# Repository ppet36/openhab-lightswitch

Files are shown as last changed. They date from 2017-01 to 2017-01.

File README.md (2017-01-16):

# OpenHAB light switch

This repository encapsulates Cadsoft's Eagle files and firmware for OpenHAB light switch using ESP8266-01 module. There is single variant under switch with relay and single/double variants with relays/triacs for round wiring boxes.

For powering module can be used any 5V/ >=800mA power supply such as USB charger for phone. Power consumption with AKYGA CCABKEYAKY-07310 power supply is about 1.2W.

Schematics is very simple. For single variant GPIO0 of ESP8266 is used for driving relay/triac and GPIO2 for observation of original switch. Light can be turned on / off using original switch or OpenHAB admin screen. For double variant is used I/O expander PCA9536 which two pins used for driving relays/triacs and other two for switches observation.

For uploading code to ESP8266 is needed Arduino. In source code is needed to specify WIFI AP parameters, network parameters, OpenHAB item name as well as address where OpenHAB server listens. After module startup is on his IP address available HTTP server where some parameters can be redefined. It's useful in case for example changing WIFI password.

For handle lightswitch in OpenHAB you need to modify you sitemap, items and rules file. In items file (/configurations/items/&lt;yourname&gt;.items) is needed to define new item:
```
Switch bathroomMirror "Bathroom (mirror light)"
```
Now you can define rule in rules file (/configurations/rules/&lt;yourname&gt;.rules), which sends request to IP address of module whenever the status changes. Instead of 192.168.128.200 is need to specify IP address of your module.
```
rule bathroomMirror
when
  Item bathroomMirror changed
then 
  if (bathroomMirror.state == ON) {
    sendHttpGetRequest("http://192.168.128.200:80/ON")
  } else {
    sendHttpGetRequest("http://192.168.128.200:80/OFF")
  }
end 
```
Finally can be switch presented in sitemap file (/configurations/sitemaps/&lt;yourname&gt;.sitemap):
```
Switch item=bathroomMirror
```
It's easy and it looks pretty good:



##Schematics:
### Single relay
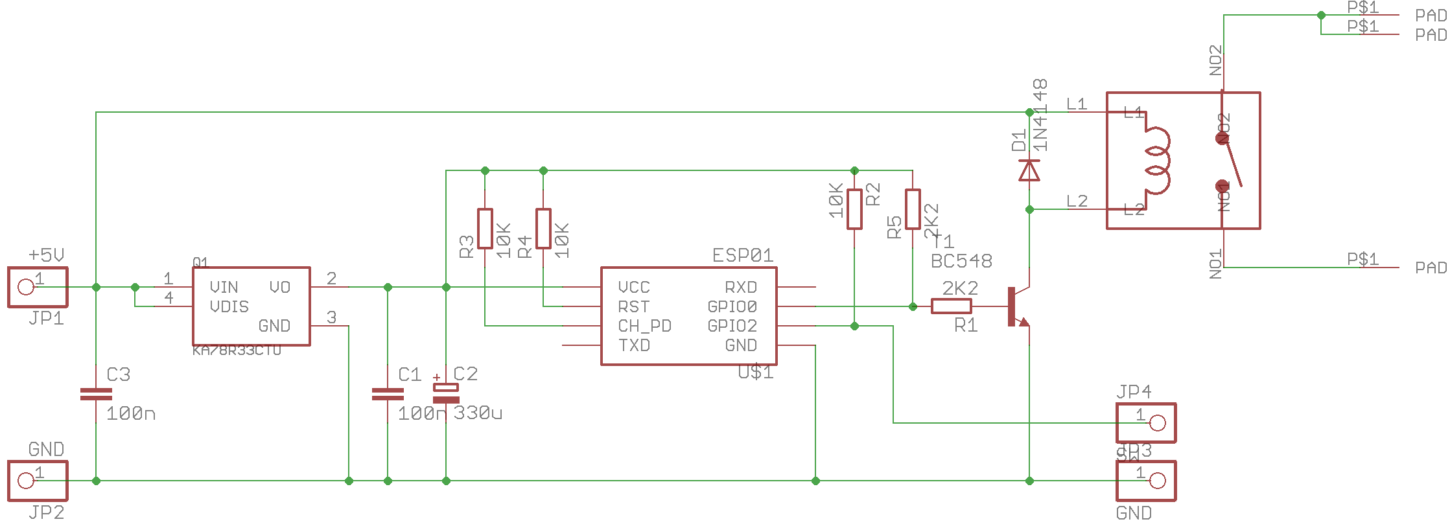
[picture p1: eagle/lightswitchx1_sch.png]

### Double relay
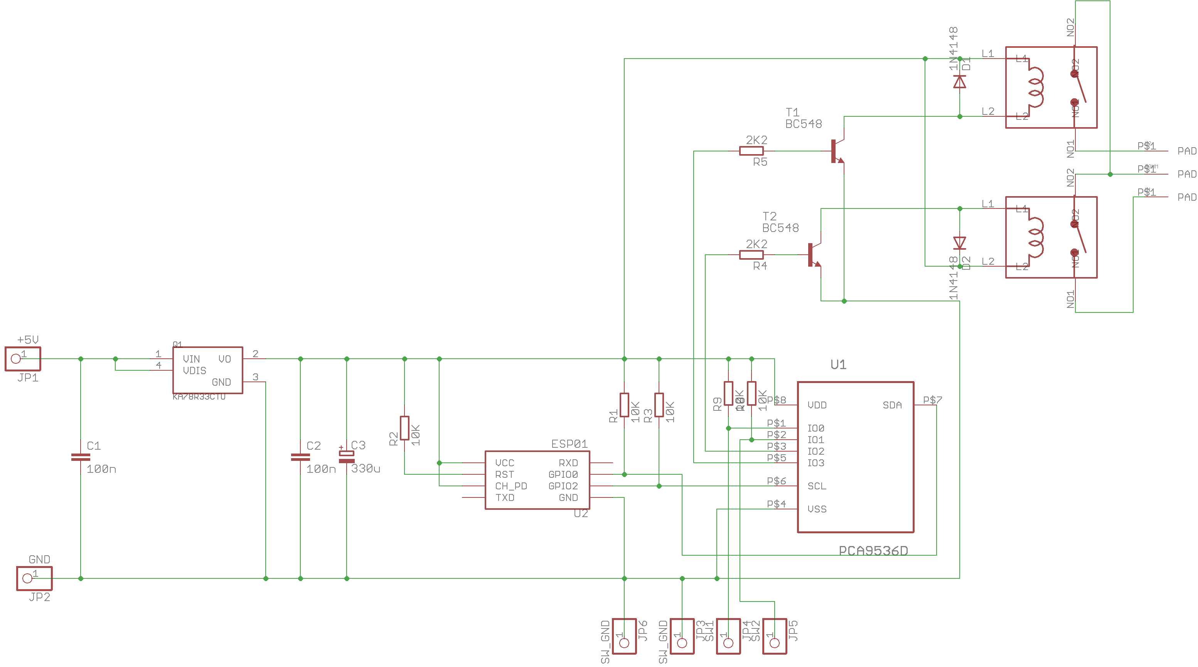
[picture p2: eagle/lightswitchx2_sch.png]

### Single triac
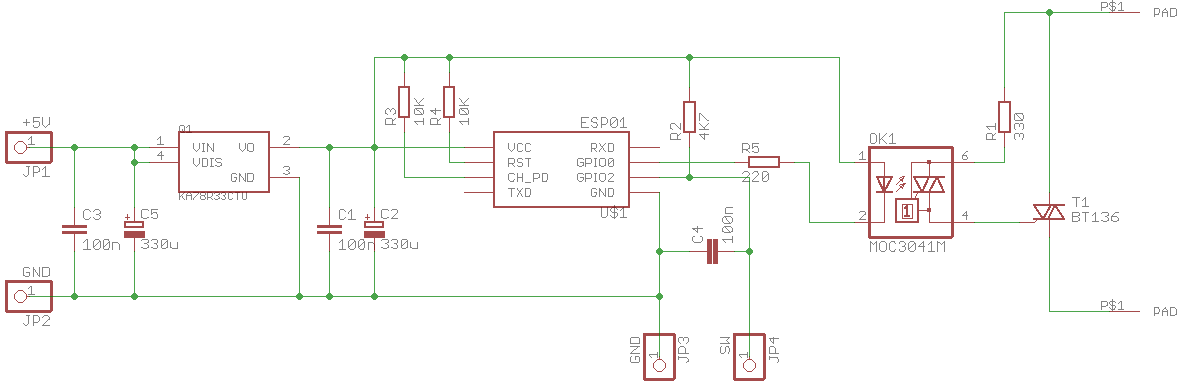
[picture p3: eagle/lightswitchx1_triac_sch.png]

### Double triac
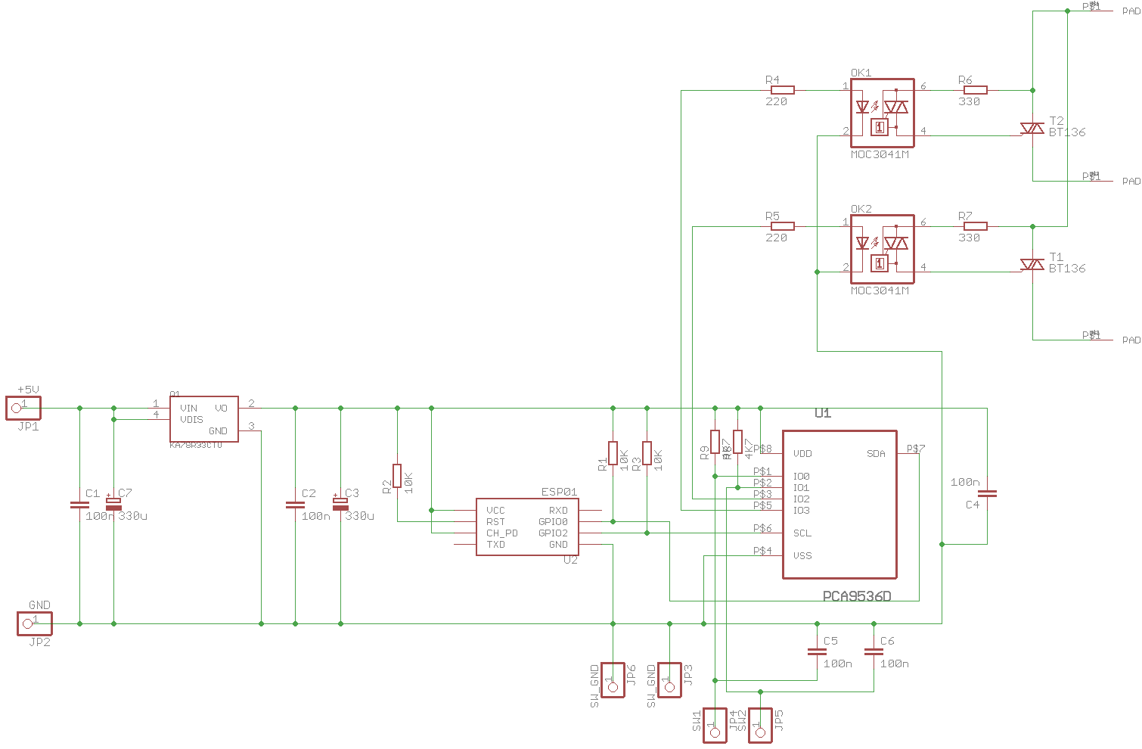
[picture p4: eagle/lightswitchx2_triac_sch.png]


##PCBs:
PCB is realized as single-sided with some wire jumpers. ESP8266 is mounted as always in socket to enable firmware update. Depending of interferences you may need solder some 100n capacitors directly to ICs pads from bottom side of PCB.

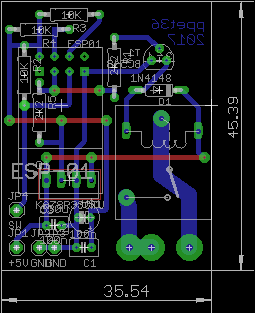
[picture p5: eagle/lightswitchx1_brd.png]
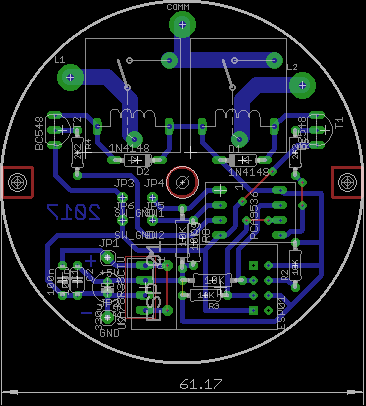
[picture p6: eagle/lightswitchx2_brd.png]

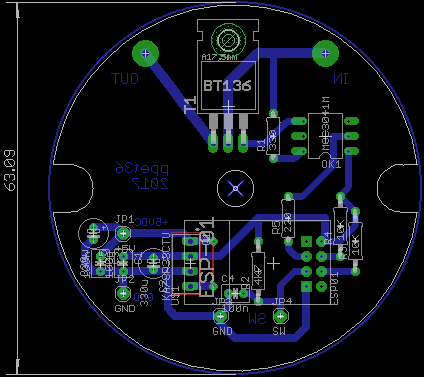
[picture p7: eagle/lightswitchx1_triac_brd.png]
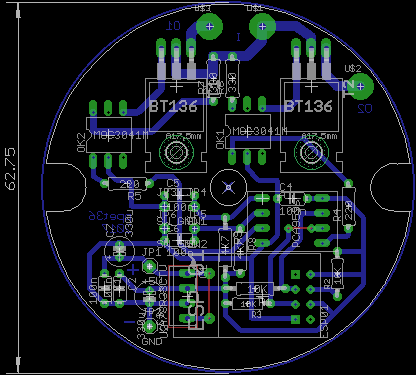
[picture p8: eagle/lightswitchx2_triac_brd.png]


###Some project images:

Module with power supply

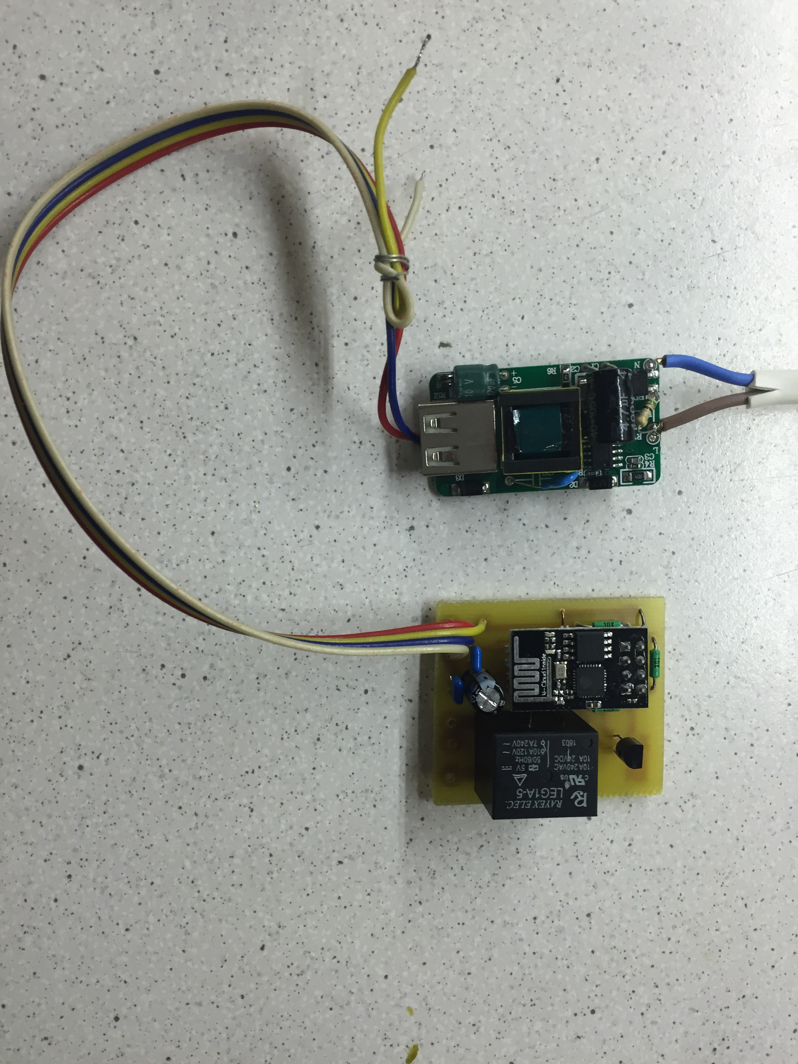
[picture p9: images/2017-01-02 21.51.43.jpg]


Already mounted on its place

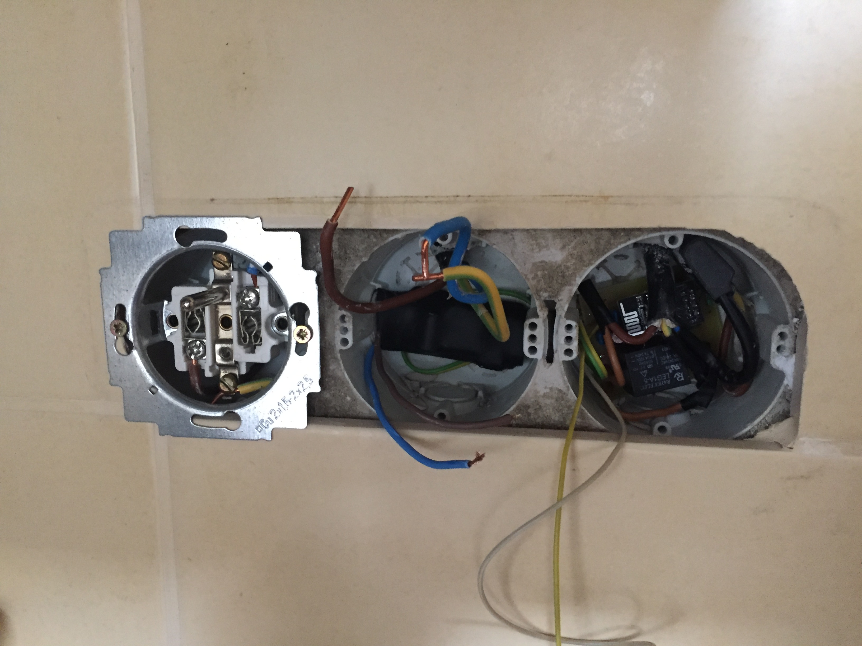
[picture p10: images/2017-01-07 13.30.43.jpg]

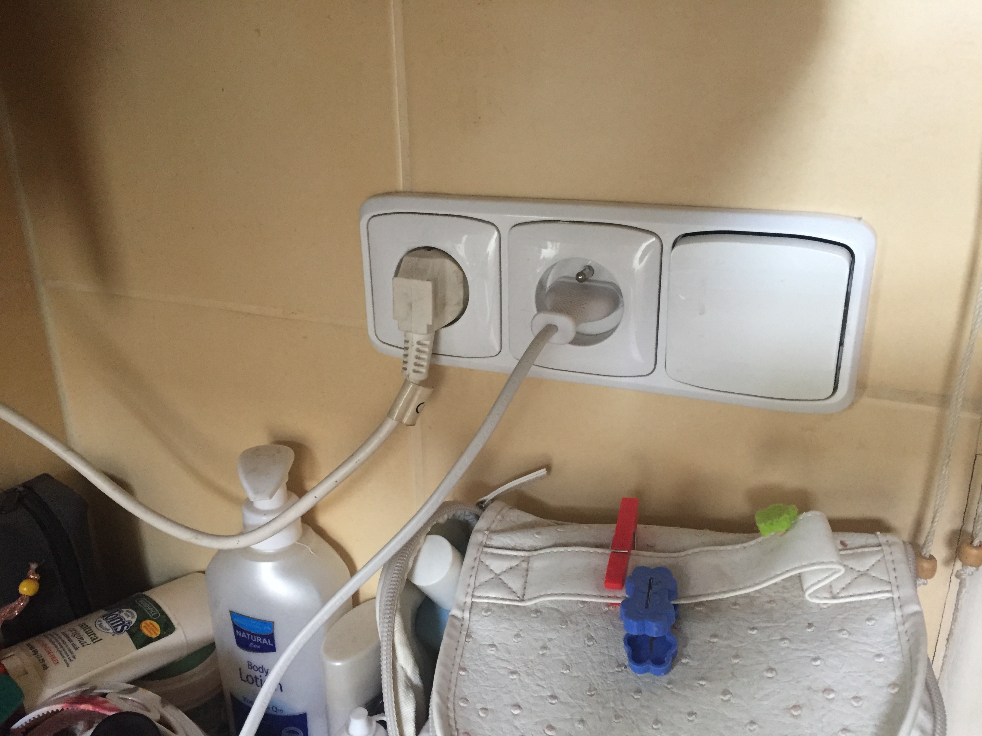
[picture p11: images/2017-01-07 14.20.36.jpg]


PCA9536 breadboard modules

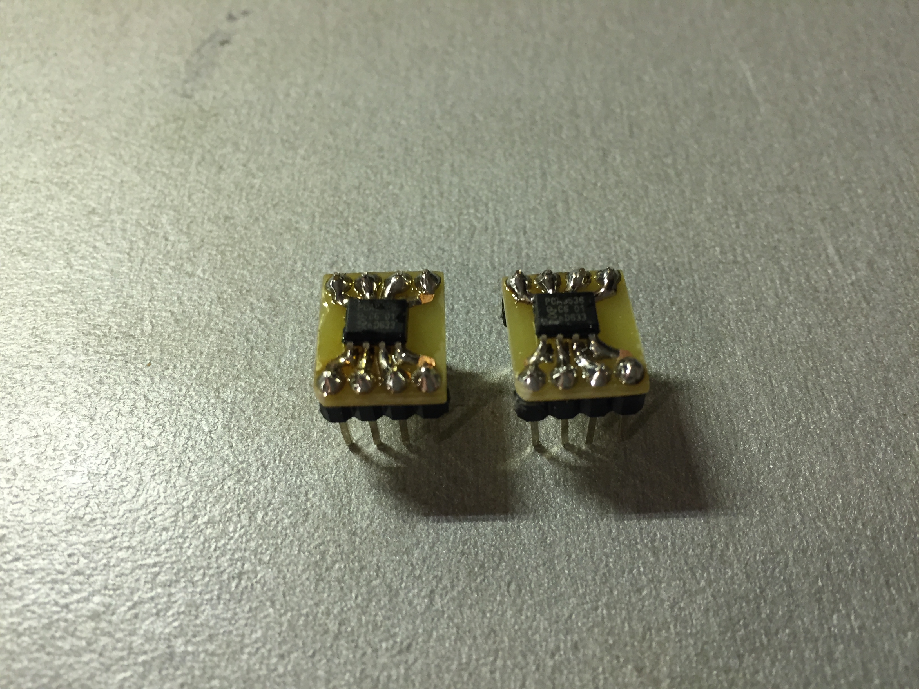
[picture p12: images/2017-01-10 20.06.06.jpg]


Double relay version

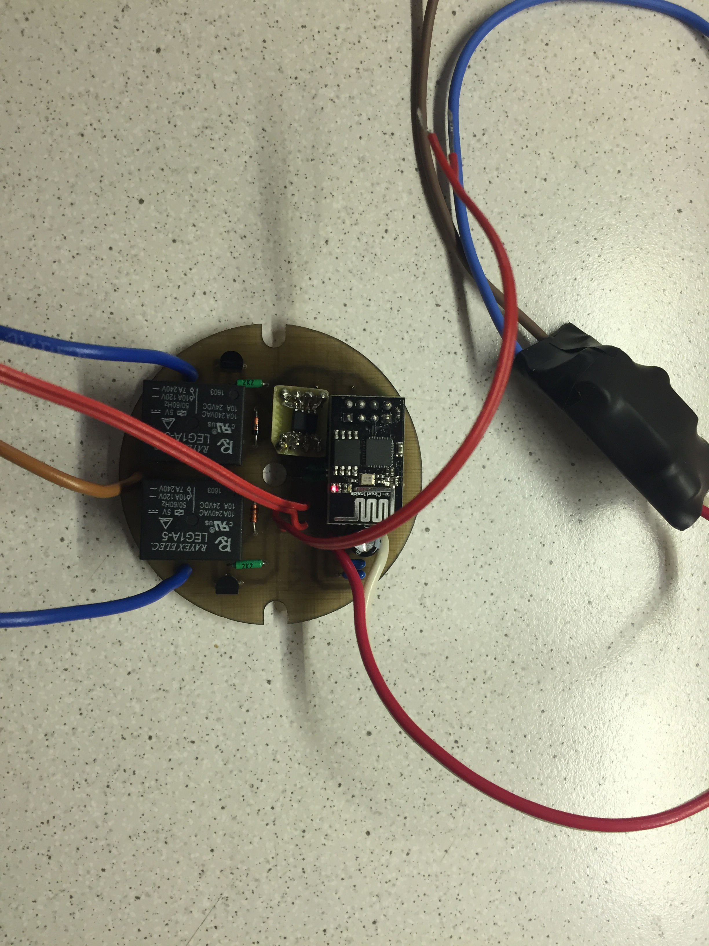
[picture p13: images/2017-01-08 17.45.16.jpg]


Single triac version

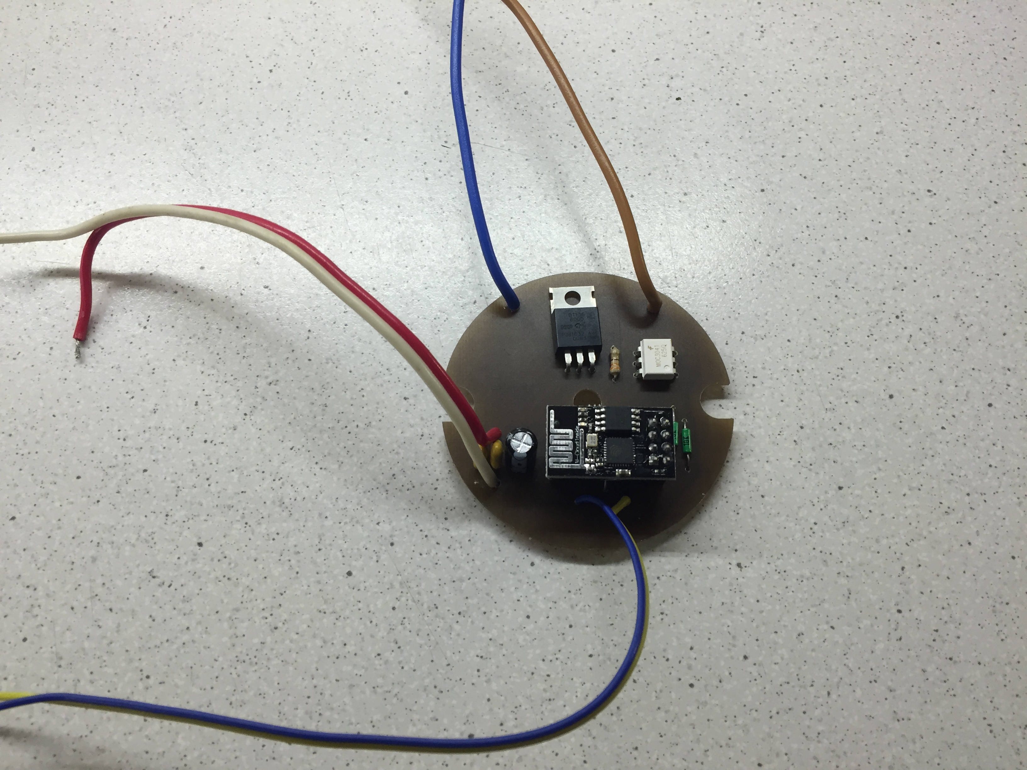
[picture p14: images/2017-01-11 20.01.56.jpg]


Double triac version

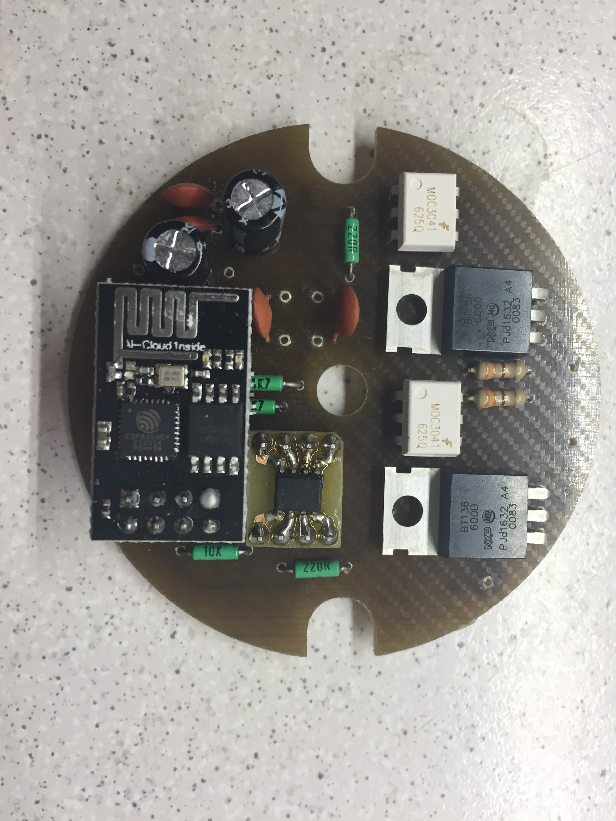
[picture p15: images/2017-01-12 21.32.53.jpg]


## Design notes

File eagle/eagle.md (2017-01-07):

This is schematic and PCB files for Cadsoft's Eagle.

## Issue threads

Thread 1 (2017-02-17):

How to load code on ESP8266

jamipraveeen, 2017-02-17:
I need to automate my applianes using OPENHAB2.I have installed Openhab2 on my raspberry pi and now my problem is how to control relays according to the user input using ESP8266.Can I control without Esp8266 ?I mean only with relay board connecting inputs to GPIO Pins of Raspberry pi? If not please provide me circuit diagram for connection

ppet36, 2017-02-21:
Here is short tutorial how to connect relay to raspberrypi gpio pin http://www.susa.net/wordpress/2012/06/raspberry-pi-relay-using-gpio/. On OpenHab website is also information how to map gpio pin to item: https://github.com/openhab/openhab1-addons/wiki/GPIO-Binding

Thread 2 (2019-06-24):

Connect original light switch on GPIO2

MaikoHermans, 2019-06-24:
I'm currently building a similar switch, however I'm not sure on how to track the state when the hardware switch is used. Do I need to connect a wire from the hardware switch to the board as well?

I'm actually using a relay board specifically made for the esp01 (see link) I would love to hear how to set this part up since I'm not sure how to make sense of the schematics you posted.

https://www.aliexpress.com/item/5V-ESP8266-ESP-01-Wifi-Relay-Module-Wireless-App-Remote-Control-IOT-Relay-Switch-ESP8266-ESP01/32963300866.html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

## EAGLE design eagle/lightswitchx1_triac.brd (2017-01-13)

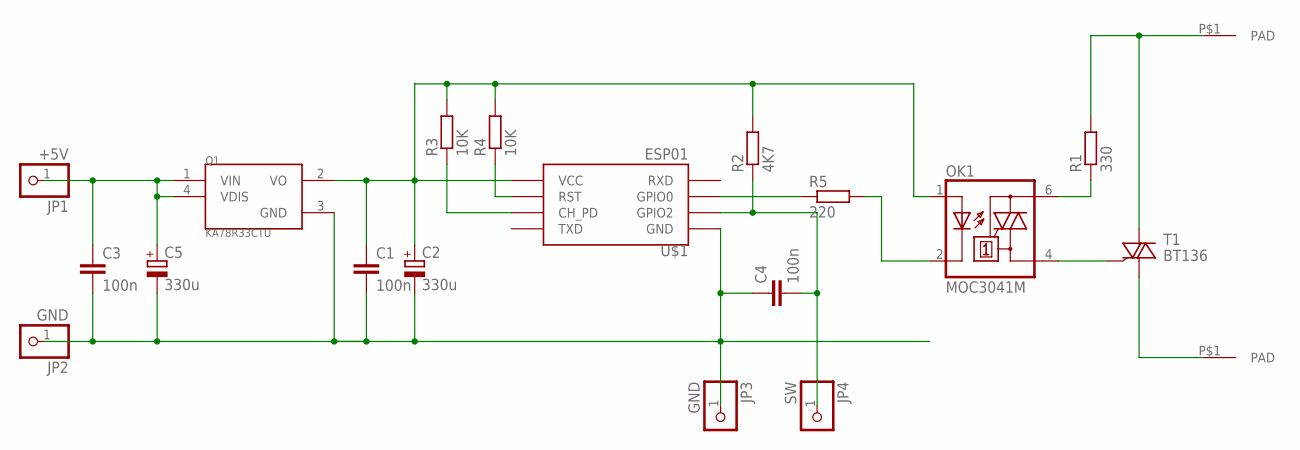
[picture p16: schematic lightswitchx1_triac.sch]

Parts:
C1, C3, C4: 100n; C025-030X050
C2, C5: 330u; E2-5
JP1: +5V; 1X01
JP2, JP3: GND; 1X01
JP4: SW; 1X01
OK1: MOC3041M; DIL06
Q1: KA78R33CTU; TO-220-4
R1: 330; 0207/7
R2: 4K7; 0207/10
R3, R4: 10K; 0207/10
R5: 220; 0207/7
T1: BT136; TO220AB
U$1: ESP01
U$4, U$5: PAD

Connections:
unnamed: C4.2, JP4.1, R2.1, U$1.GPIO2
unnamed: C1.2, C2.-, C3.2, C4.1, C5.-, JP2.1, JP3.1, Q1.3 (GND), U$1.GND
unnamed: C1.1, C2.+, OK1.1 (A), Q1.2 (VO), R2.2, R3.2, R4.2, U$1.VCC
unnamed: OK1.4 (A1), T1.3 (G)
unnamed: C3.1, C5.+, JP1.1, Q1.1 (VIN), Q1.4 (VDIS)
unnamed: R5.1, U$1.GPIO0
unnamed: OK1.6 (A2), R1.1
unnamed: R4.1, U$1.RST
unnamed: R3.1, U$1.CH_PD
unnamed: R1.2, T1.2 (A2), U$5.P$1
unnamed: T1.1 (A1), U$4.P$1
unnamed: OK1.2 (C), R5.2

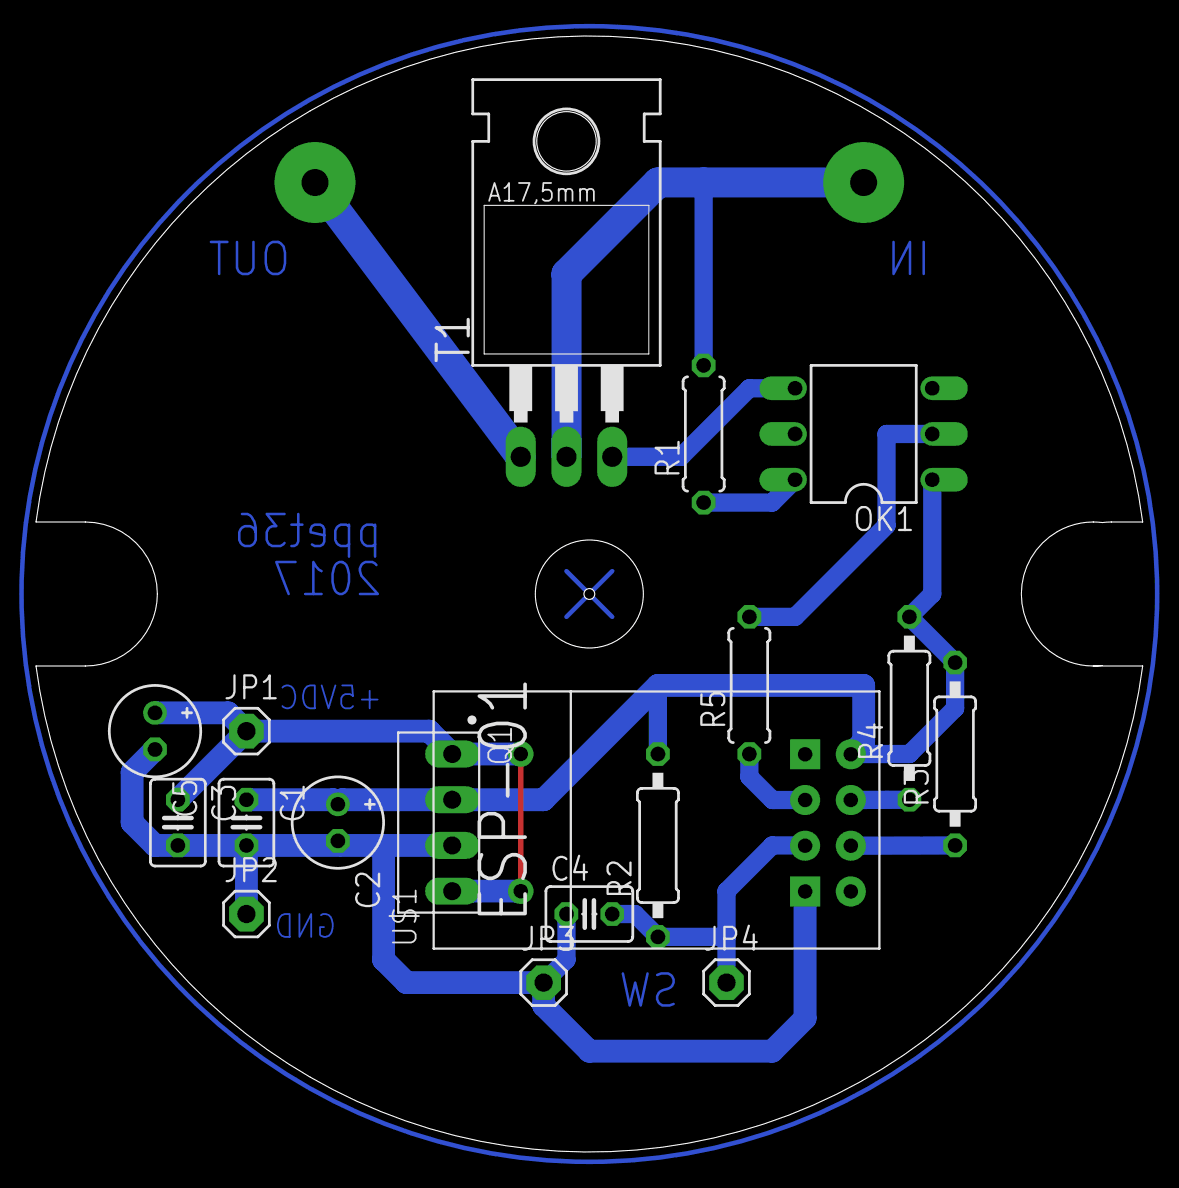
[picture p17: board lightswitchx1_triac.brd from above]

Board: 2 copper layers, 61.5 x 62.0 mm, 20 parts (0 on the bottom side), 12 nets.

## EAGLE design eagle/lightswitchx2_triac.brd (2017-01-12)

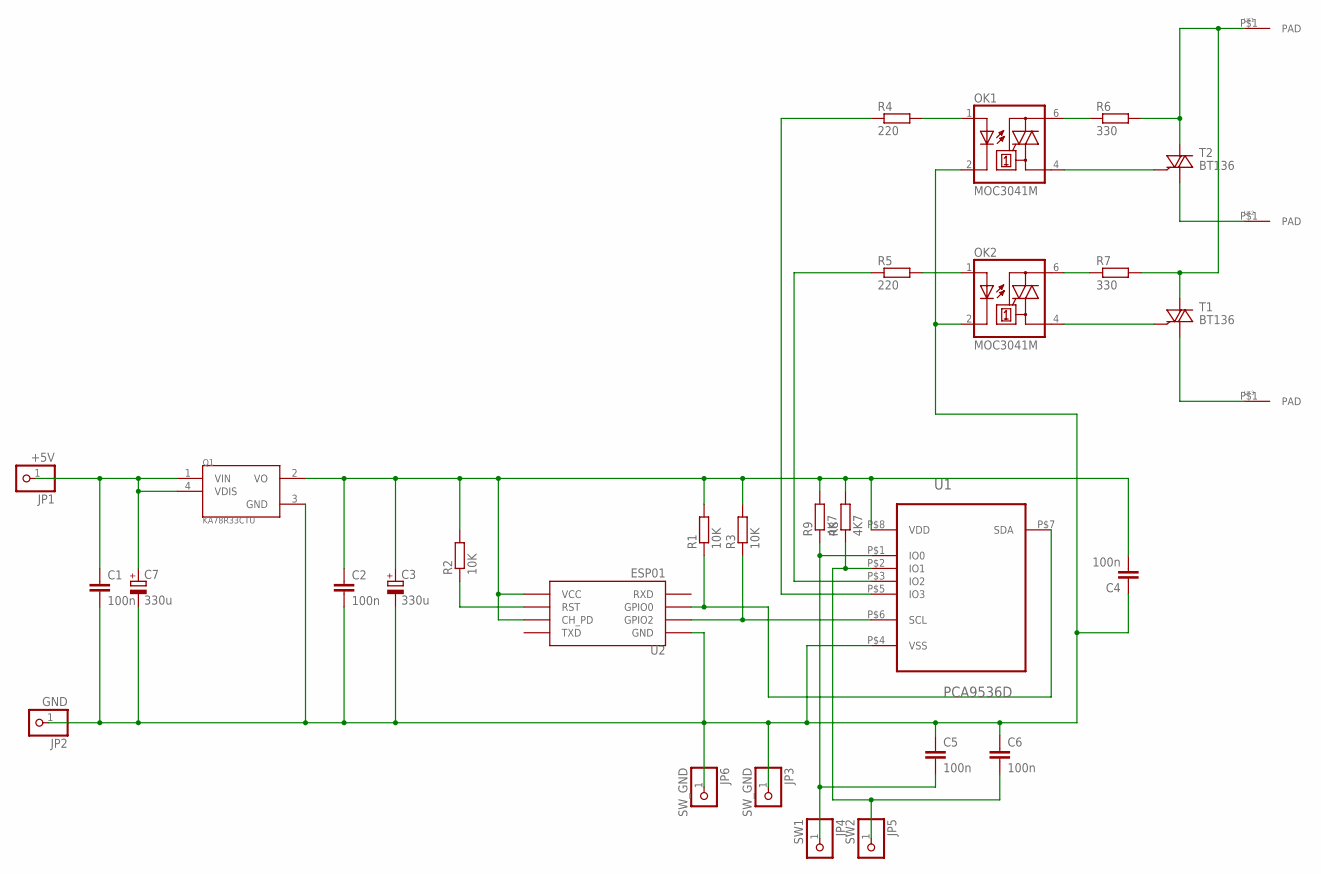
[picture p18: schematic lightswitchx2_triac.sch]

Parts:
C1, C2, C4, C5, C6: 100n; C050-024X044
C3, C7: 330u; E2-5
JP1: +5V; 1X01
JP2: GND; 1X01
JP3, JP6: SW_GND; 1X01-CLEANBIG
JP4: SW1; 1X01-CLEANBIG
JP5: SW2; 1X01-CLEANBIG
OK1, OK2: MOC3041M; DIL06
Q1: KA78R33CTU; TO-220-4
R1: 10K; 0207/10
R2, R3: 10K; 0204/7
R4, R5: 220; 0207/7
R6, R7: 330; 0207/7
R8: 4K7; 0207/7
R9: 4K7; 0207/10
T1, T2: BT136; TO220AB
U1: PCA9536D; ADAPTER
U2: ESP01
U$1, U$2, U$3: PAD

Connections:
unnamed: C1.1, C7.+, JP1.1, Q1.1 (VIN), Q1.4 (VDIS)
unnamed: R4.1, U1.P$5 (IO3)
unnamed: OK1.1 (A), R4.2
unnamed: R1.1, U1.P$7 (SDA), U2.GPIO0
unnamed: OK2.1 (A), R5.2
unnamed: R3.1, U1.P$6 (SCL), U2.GPIO2
unnamed: R2.1, U2.RST
unnamed: OK2.6 (A2), R7.1
unnamed: R5.1, U1.P$3 (IO2)
unnamed: OK1.6 (A2), R6.1
unnamed: C5.2, JP4.1, R9.1, U1.P$1 (IO0)
unnamed: R6.2, R7.2, T1.2 (A2), T2.2 (A2), U$1.P$1
unnamed: C6.2, JP5.1, R8.1, U1.P$2 (IO1)
unnamed: OK1.4 (A1), T2.3 (G)
unnamed: OK2.4 (A1), T1.3 (G)
unnamed: T2.1 (A1), U$2.P$1
unnamed: T1.1 (A1), U$3.P$1
VDD: C2.1, C3.+, C4.2, Q1.2 (VO), R1.2, R2.2, R3.2, R8.2, R9.2, U1.P$8 (VDD), U2.CH_PD, U2.VCC
VSS: C1.2, C2.2, C3.-, C4.1, C5.1, C6.1, C7.-, JP2.1, JP3.1, JP6.1, OK1.2 (C), OK2.2 (C), Q1.3 (GND), U1.P$4 (VSS), U2.GND

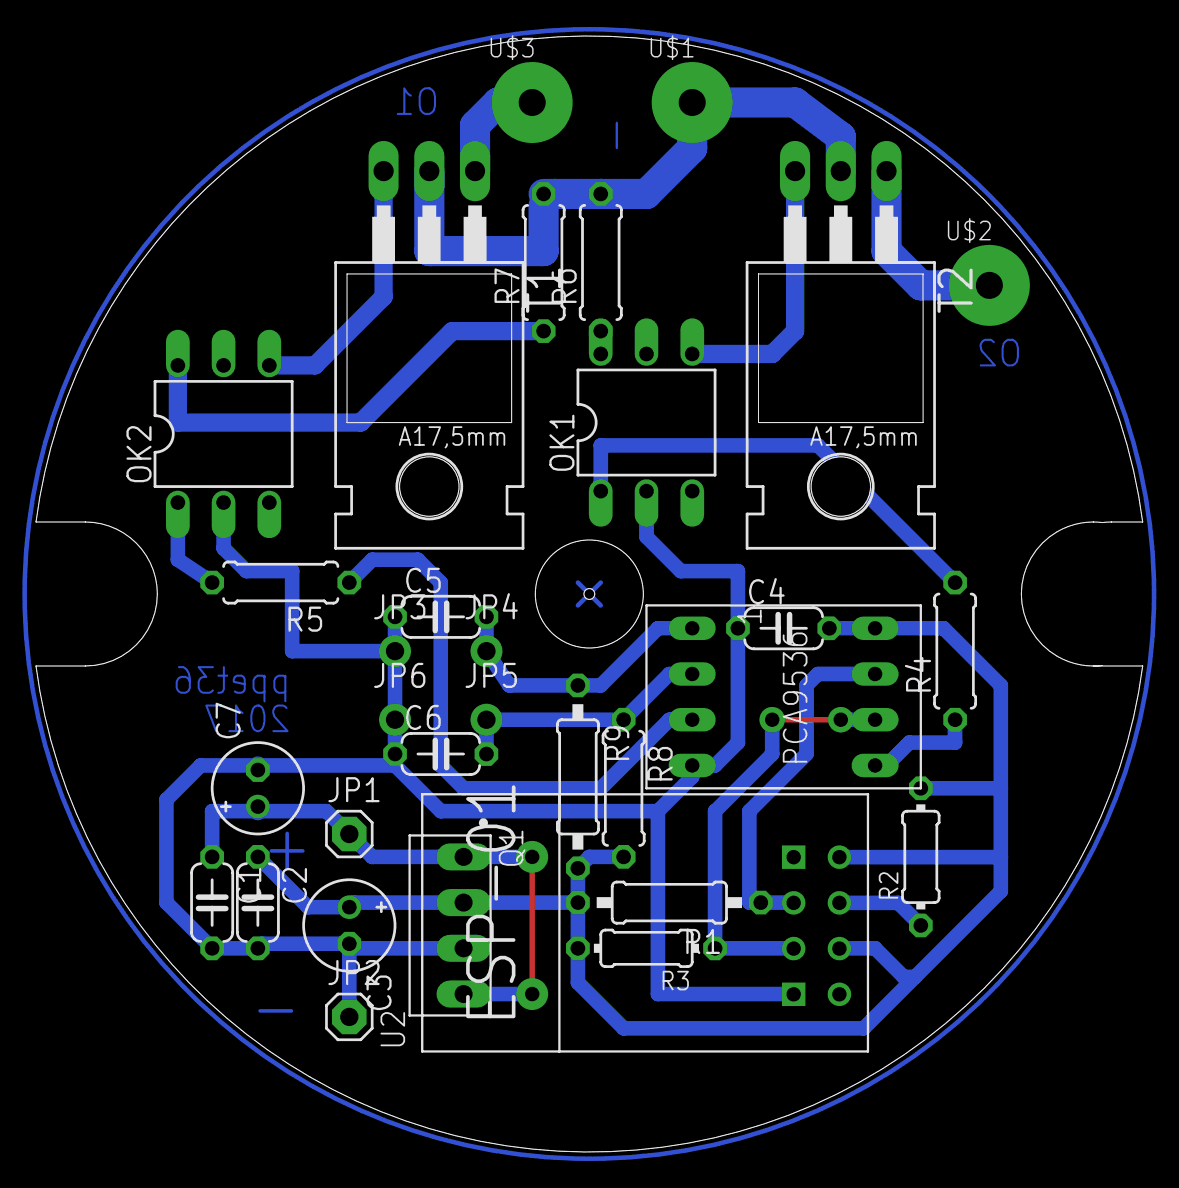
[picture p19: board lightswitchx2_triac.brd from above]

Board: 2 copper layers, 61.5 x 62.0 mm, 32 parts (0 on the bottom side), 19 nets.

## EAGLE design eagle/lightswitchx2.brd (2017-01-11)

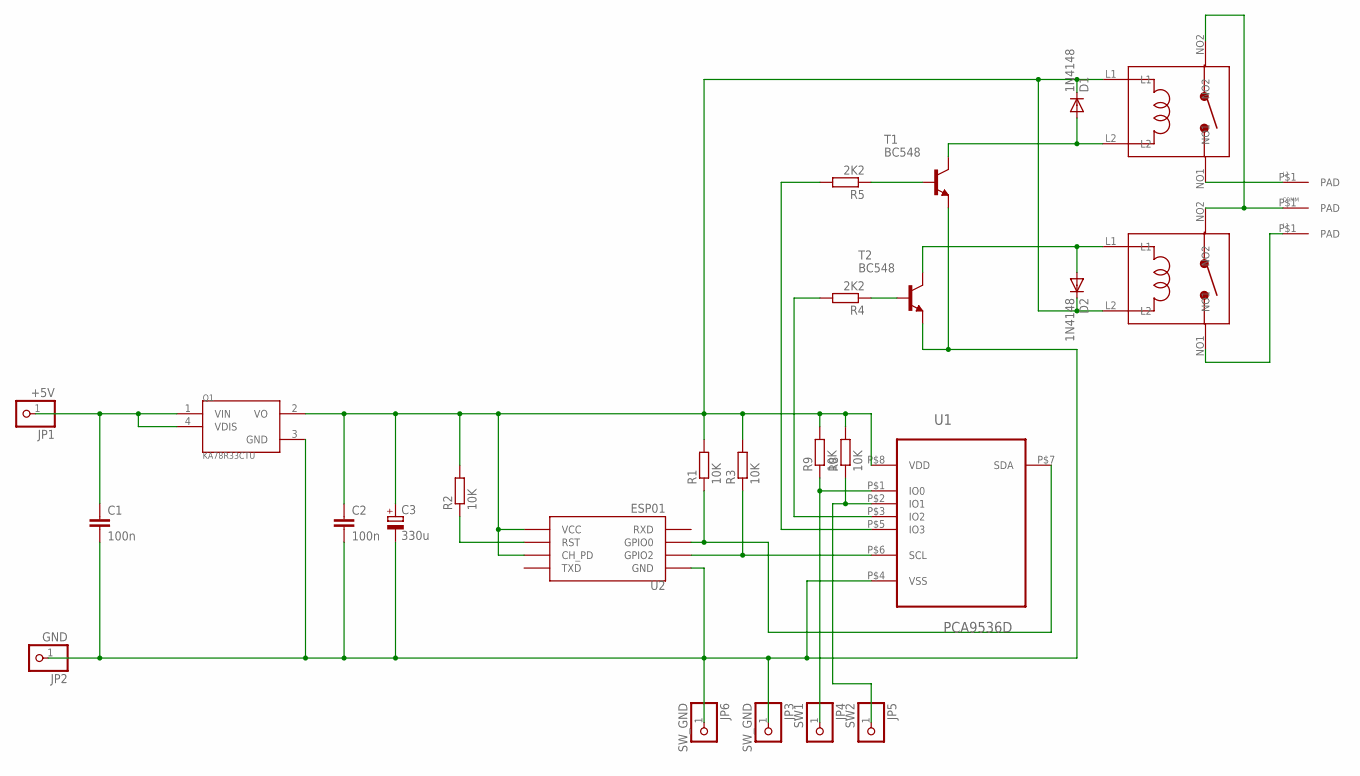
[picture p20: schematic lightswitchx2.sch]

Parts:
C1, C2: 100n; C050-024X044
C3: 330u; E2-5
COMM: PAD
D1, D2: 1N4148; DO35-7
JP1: +5V; 1X01
JP2: GND; 1X01
JP3, JP6: SW_GND; 1X01-CLEANBIG
JP4: SW1; 1X01-CLEANBIG
JP5: SW2; 1X01-CLEANBIG
L1: L1; PAD
L2: X; PAD
Q1: KA78R33CTU; TO-220-4
R1, R9: 10K; 0207/10
R2, R3: 10K; 0204/7
R4, R5: 2K2; 0204/7
R8: 10K; 0207/7
REL1, REL2: LEG1A-5; LEG-1A-5
T1, T2: BC548; TO92-EBC
U1: PCA9536D; ADAPTER
U2: ESP01

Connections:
unnamed: C1.1, JP1.1, Q1.1 (VIN), Q1.4 (VDIS)
unnamed: R5.2, U1.P$5 (IO3)
unnamed: L1.P$1, REL1.NO1
unnamed: R1.1, U1.P$7 (SDA), U2.GPIO0
unnamed: COMM.P$1, REL1.NO2, REL2.NO2
unnamed: R3.1, U1.P$6 (SCL), U2.GPIO2
unnamed: R2.1, U2.RST
unnamed: R5.1, T1.B
unnamed: R4.2, U1.P$3 (IO2)
unnamed: R4.1, T2.B
unnamed: JP4.1, R9.1, U1.P$1 (IO0)
unnamed: L2.P$1, REL2.NO1
unnamed: D1.A, REL2.L2, T1.C
unnamed: JP5.1, R8.1, U1.P$2 (IO1)
unnamed: D2.A, REL1.L1, T2.C
VDD: C2.1, C3.+, D1.C, D2.C, Q1.2 (VO), R1.2, R2.2, R3.2, R8.2, R9.2, REL1.L2, REL2.L1, U1.P$8 (VDD), U2.CH_PD, U2.VCC
VSS: C1.2, C2.2, C3.-, JP2.1, JP3.1, JP6.1, Q1.3 (GND), T1.E, T2.E, U1.P$4 (VSS), U2.GND

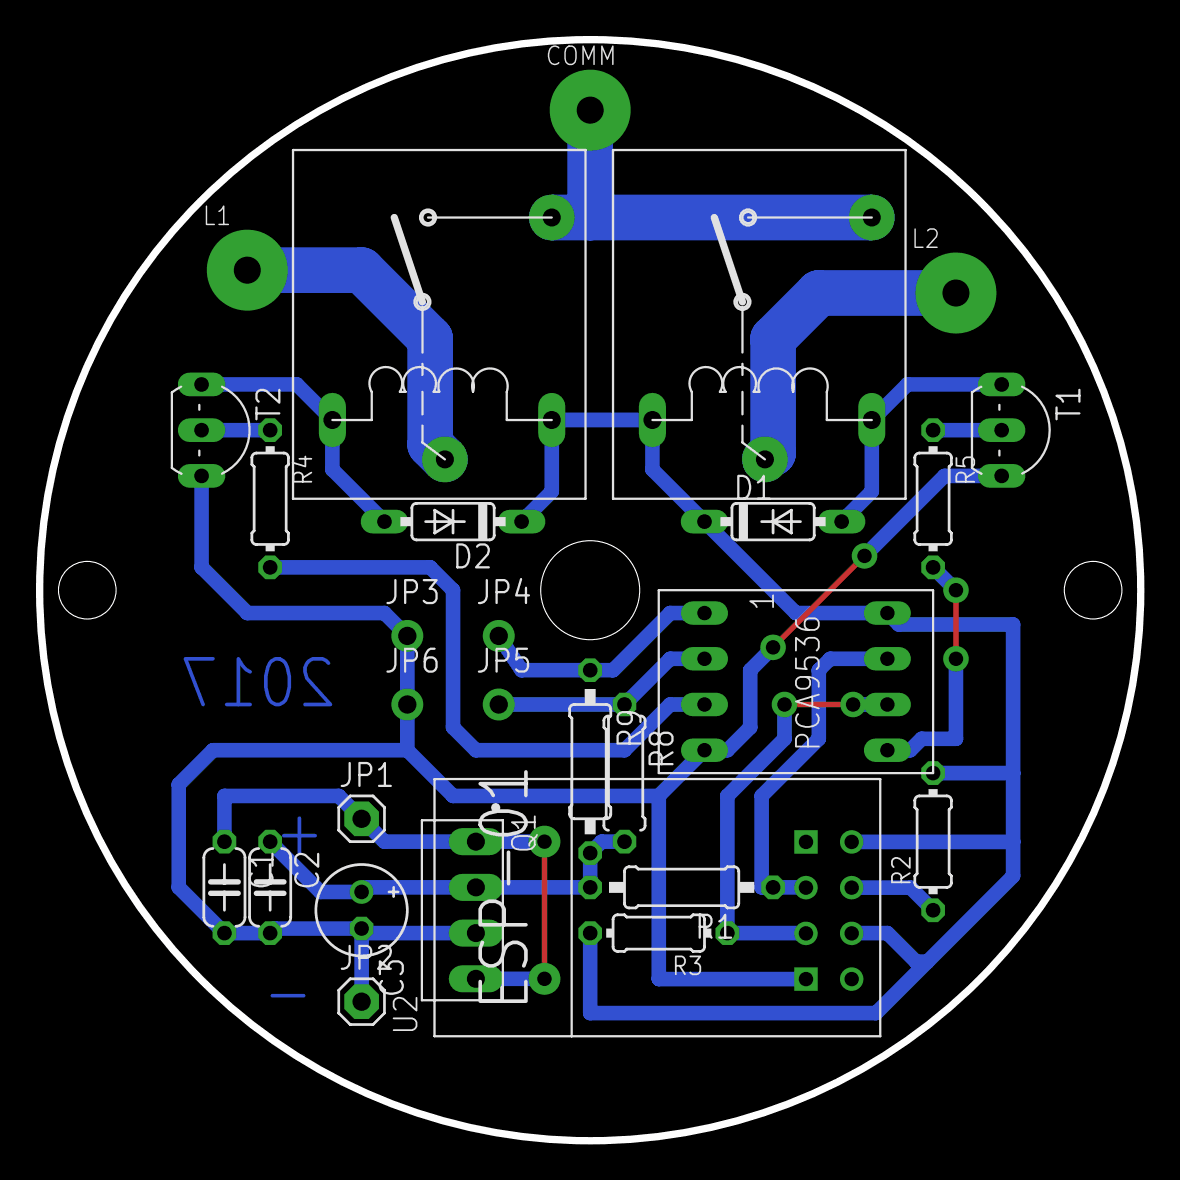
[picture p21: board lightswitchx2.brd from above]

Board: 2 copper layers, 61.2 x 61.2 mm, 28 parts (0 on the bottom side), 17 nets.

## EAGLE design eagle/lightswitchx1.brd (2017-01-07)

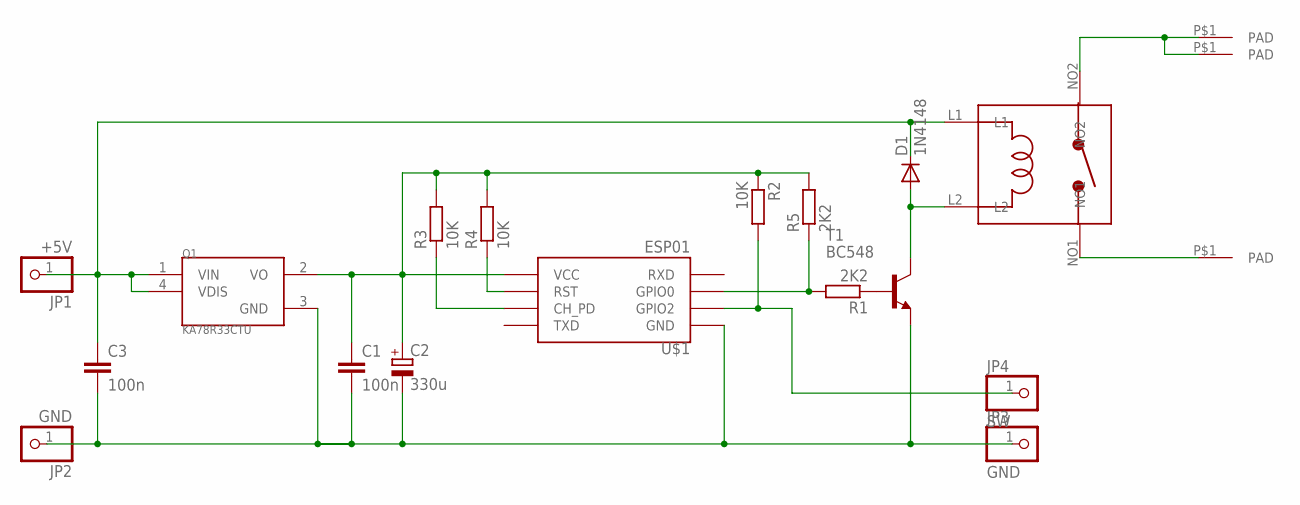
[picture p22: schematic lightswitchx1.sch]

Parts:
C1, C3: 100n; C025-030X050
C2: 330u; E2-5
D1: 1N4148; DO35-7
JP1: +5V; 1X01
JP2, JP3: GND; 1X01
JP4: SW; 1X01
Q1: KA78R33CTU; TO-220-4
R1, R5: 2K2; 0207/10
R2, R3, R4: 10K; 0207/10
T1: BC548; TO92
U$1: ESP01
U$2: LEG1A-5; LEG-1A-5
U$3, U$4, U$5: PAD

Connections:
unnamed: JP4.1, R2.2, U$1.GPIO2
unnamed: C1.2, C2.-, C3.2, JP2.1, JP3.1, Q1.3 (GND), T1.1 (E), U$1.GND
unnamed: C1.1, C2.+, Q1.2 (VO), R2.1, R3.2, R4.2, R5.2, U$1.VCC
unnamed: D1.A, T1.3 (C), U$2.L2
unnamed: C3.1, D1.C, JP1.1, Q1.1 (VIN), Q1.4 (VDIS), U$2.L1
unnamed: R1.2, R5.1, U$1.GPIO0
unnamed: R1.1, T1.2 (B)
unnamed: R4.1, U$1.RST
unnamed: R3.1, U$1.CH_PD
unnamed: U$2.NO2, U$3.P$1, U$5.P$1
unnamed: U$2.NO1, U$4.P$1

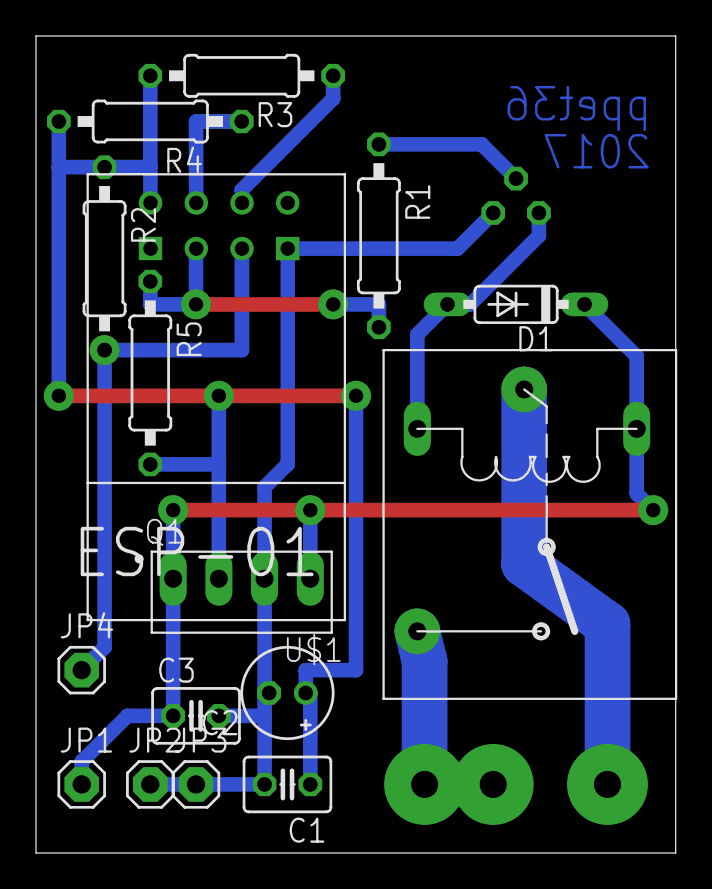
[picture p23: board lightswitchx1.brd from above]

Board: 2 copper layers, 35.5 x 45.4 mm, 20 parts (1 on the bottom side), 11 nets.

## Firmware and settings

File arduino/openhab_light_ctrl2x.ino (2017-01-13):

/**
 * Two light ON/OFF drivers with PCA9536.
*/
#include <EEPROM.h>
#include <ESP8266WiFi.h>
#include <ESP8266HTTPClient.h>
#include <WiFiClient.h>
#include <ESP8266WebServer.h>
#include <Wire.h>
#include <PCA9536.h>

// GPIO0 and GPIO2 used for I2C bus
#define SDA_PIN 0
#define SCL_PIN 2

// Local base URL of OpenHAB (can be changed later on config page)
#define DEFAULT_OPENHAB_HOST "192.168.128.100"
#define DEFAULT_OPENHAB_PORT 9000

// Name of OpenHAB item (can be changed later on config page)
#define DEFAULT_OPENHAB_ITEM1 "kitchenChandelier"
#define DEFAULT_OPENHAB_ITEM2 "WC"

// Update time for item state in seconds;
// switch periodically sends its state to OpenHAB
#define ITEM_UPDATE_TIME 60L

// Local network definition; must have static IP address
#define LOCAL_IP IPAddress(192, 168, 128, 201)
#define GATEWAY IPAddress(192, 168, 128, 1)
#define SUBNETMASK IPAddress(255, 255, 255, 0)

// Local Wifi AP for connect
#define DEFAULT_WIFI_AP "******"
#define DEFAULT_WIFI_PASSWORD "********"

// Error count for reconnect WIFI
#define ERR_COUNT_FOR_RECONNECT 30
#define HTTP_READ_TIMEOUT       10000
#define HTTP_CONNECT_TIMEOUT    5000

// Local WEB server port
#define WEB_SERVER_PORT 80

// Magic for detecting empty (unconfigured) EEPROM
#define MAGIC 0xAC

// Configuration server
ESP8266WebServer *server = (ESP8266WebServer *) NULL;

// Last interaction time
long lastInteractionTime;

// Number of communication errors
int errorCount = 0;

/** Current light states. */
bool lightState [2];

/**
 * Struktura ukladana do EEPROM.
*/
struct OhConfiguration {
  int magic;
  char apName [24];
  char password [48];
  char openhabItem1 [50];
  char openhabItem2 [50];
  char openhabHost [50];
  unsigned int openhabPort;
};

// Configuration
OhConfiguration config;

// PCA9536 communication object
PCA9536 pca;

/**
 * Setup function.
*/
void setup() {
  // serial
  Serial.begin (115200);
  delay (5000);
  Serial.println ("setup()");
  
  Wire.begin (SDA_PIN, SCL_PIN);

  lightState [0] = false;
  lightState [1] = false;

  pcaSetup();


  // Read config
  EEPROM.begin (sizeof (OhConfiguration));
  EEPROM.get (0, config);
  if (config.magic != MAGIC) {
    memset (&config, 0, sizeof (OhConfiguration));
    config.magic = MAGIC;
    updateConfigKey (config.apName, 24, String(DEFAULT_WIFI_AP));
    updateConfigKey (config.password, 48, String(DEFAULT_WIFI_PASSWORD));
    updateConfigKey (config.openhabItem1, 50, String(DEFAULT_OPENHAB_ITEM1));
    updateConfigKey (config.openhabItem2, 50, String(DEFAULT_OPENHAB_ITEM2));
    updateConfigKey (config.openhabHost, 50, String(DEFAULT_OPENHAB_HOST));
    config.openhabPort = DEFAULT_OPENHAB_PORT;
  }

  reconnectWifi();
  createServer();

  delay (1000);
}

/**
 * Configure PCA.
*/
void pcaSetup() {
  pca.reset();
  pca.setMode (IO0, IO_INPUT);
  pca.setMode (IO1, IO_INPUT);
  pca.setMode (IO2, IO_OUTPUT);
  pca.setMode (IO3, IO_OUTPUT);
  pca.setState (IO2, lightState[0] ? IO_HIGH : IO_LOW);
  pca.setState (IO3, lightState[1] ? IO_HIGH : IO_LOW);

  while (pca.ping()) {
    Serial.println("Not Found");
    delay (100);
  }
}

/**
 * Helper routine; updates config key.
 *
 * @param c key.
 * @param len max length.
 * @param val value.
*/
void updateConfigKey (char *c, int len, String val) {
  memset (c, 0, len);
  sprintf (c, "%s", val.c_str());
}

/**
 * Reconects WIFI.
*/
void reconnectWifi() {
  Serial.println ("WiFi disconnected...");
  WiFi.disconnect();
  String hostname = String("openhab_") + String(config.openhabItem1) + String("_") + String(config.openhabItem2);
  WiFi.hostname (hostname);
  WiFi.config (LOCAL_IP, GATEWAY, SUBNETMASK);
  WiFi.mode (WIFI_STA);
  delay (1000);

  Serial.print ("Connecting to "); Serial.print (WIFI_AP); Serial.print (' ');
  WiFi.begin (config.apName, config.password);
  delay (1000);
  while (WiFi.status() != WL_CONNECTED) {
    yield();
    delay (500);
    Serial.print (".");
  }
  delay (500);
  Serial.println();
  Serial.println ("WiFi connected...");
}

/**
 * Creates HTTP server.
*/
void createServer() {
  if (server) {
    server->close();
    delete server;
    server = NULL;
  }
  
  // ... and run HTTP server for setup
  server = new ESP8266WebServer (LOCAL_IP, WEB_SERVER_PORT);
  server->on ("/OFF/1", wsLightOff1);
  server->on ("/ON/1", wsLightOn1);
  server->on ("/OFF/2", wsLightOff2);
  server->on ("/ON/2", wsLightOn2);
  server->on ("/", wsConfig);
  server->on ("/update", wsUpdate);
  server->on ("/reconnect", wsReconnect);
  server->begin();

  Serial.println ("Created server...");
}

/**
 * Physically turn light on.
 * 
 * @param index index.
*/
void lightOn (byte index) {
  yield();
  lightState [index] = true;
  pca.setState (index == 0 ? IO2 : IO3, IO_HIGH);
}

/**
 * Physisally turn light off.
 * 
 * @param index index.
*/
void lightOff (byte index) {
  yield();
  lightState [index] = false;
  pca.setState (index == 0 ? IO2 : IO3, IO_LOW);

  if (!lightState [0] && !lightState [1]) {
    delay (250);
    pcaSetup();
  }
}

/**
 * Light OFF for WEB server.
*/
void wsLightOff1() {
  Serial.println ("Received command OFF for light1...");
  lightOff(0);
  server->send (200, "text/html", "");
}

/**
 * Light ON for WEB server.
*/
void wsLightOn1() {
  Serial.println ("Received command ON for light1...");
  lightOn(0);
  server->send (200, "text/html", "");
}

/**
 * Light OFF for WEB server.
*/
void wsLightOff2() {
  Serial.println ("Received command OFF for light2...");
  lightOff(1);
  server->send (200, "text/html", "");
}

/**
 * Light ON for WEB server.
*/
void wsLightOn2() {
  Serial.println ("Received command ON for light2...");
  lightOn(1);
  server->send (200, "text/html", "");
}

/**
 * Returns switch state.
 * 
 * @param index index.
 * @return bool state.
*/
bool getSwitchState (byte index) {
  return pca.getState ((index == 0) ? IO0 : IO1);
}

/**
 * Configuration page.
*/
void wsConfig() {
  yield();

  String resp = "<html><head><title>OpenHAB double switch configuration</title>";
  resp += "<meta name=\"viewport\" content=\"initial-scale=1.0, width = device-width, user-scalable = no\">";
  resp += "</head><body>";
  resp += "<h1>OpenHAB switch configuration</h1>";
  resp += "<form method=\"post\" action=\"/update\" id=\"form\">";
  resp += "<table border=\"0\" cellspacing=\"0\" cellpadding=\"5\">";
  resp += "<tr><td>AP SSID:</td><td><input type=\"text\" name=\"apName\" value=\"" + String(config.apName) + "\" maxlength=\"24\"></td><td></td></tr>";
  resp += "<tr><td>AP Password:</td><td><input type=\"password\" name=\"password\" value=\"" + String(config.password) + "\" maxlength=\"48\"></td><td></td></tr>";
  resp += "<tr><td>OpenHAB item 1:</td><td><input type=\"text\" name=\"openhabItem1\" value=\"" + String(config.openhabItem1) + "\" maxlength=\"50\"></td><td></td></tr>";
  resp += "<tr><td>OpenHAB item 2:</td><td><input type=\"text\" name=\"openhabItem2\" value=\"" + String(config.openhabItem2) + "\" maxlength=\"50\"></td><td></td></tr>";
  resp += "<tr><td>OpenHAB IP address:</td><td><input type=\"text\" name=\"openhabHost\" value=\"" + String(config.openhabHost) + "\" maxlength=\"50\"></td><td></td></tr>";
  resp += "<tr><td>OpenHAB port:</td><td><input type=\"text\" name=\"openhabPort\" value=\"" + String(config.openhabPort) + "\"></td><td></td></tr>";

  resp += "<tr><td colspan=\"3\" align=\"center\"><input type=\"submit\" value=\"Save\"></td></tr>";
  resp += "</table></form>";
  resp += "<p><a href=\"/reconnect\">Reconnect WiFi...</a></p>";
  resp += "</body></html>";

  server->send (200, "text/html", resp);
}

/**
 * Reconnects WiFi with new parameters.
*/
void wsReconnect() {
  yield();
  String resp = "<script>window.alert ('Reconnecting WiFi...'); window.location.replace ('/');</script>";
  server->send (200, "text/html", resp);
  reconnectWifi();
  createServer();
}

/**
 * Saves configuration.
*/
void wsUpdate() {
  yield();

  String apName = server->arg ("apName");
  String password = server->arg ("password");
  String openhabItem1 = server->arg ("openhabItem1");
  String openhabItem2 = server->arg ("openhabItem2");
  String openhabHost = server->arg ("openhabHost");
  unsigned int openhabPort = atoi (server->arg ("openhabPort").c_str());
  
  if (apName.length() > 1) {
    updateConfigKey (config.apName, 24, apName);
    updateConfigKey (config.password, 48, password);
    updateConfigKey (config.openhabItem1, 50, openhabItem1);
    updateConfigKey (config.openhabItem2, 50, openhabItem2);
    updateConfigKey (config.openhabHost, 50, openhabHost);
    config.openhabPort = openhabPort;
  
    // store configuration
    EEPROM.begin (sizeof (OhConfiguration));
    EEPROM.put (0, config);
    EEPROM.end();
  
    String resp = "<script>window.alert ('Configuration updated...'); window.location.replace ('/');</script>";
    server->send (200, "text/html", resp);
  } else {
    server->send (200, "text/html", "");
  }
}

/**
 * Calls URL and reads response.
 * 
 * @param url url.
 * @return String response.
*/
String communicate (String url) {
  WiFiClient client;

  // connect to OpenHAB
  Serial.print ("Connecting to "); Serial.print (config.openhabHost); Serial.print (':'); Serial.print (config.openhabPort); Serial.println ("...");
  if (client.connect (config.openhabHost, config.openhabPort)) {
    // send request
    String req = String("GET ") + url + String (" HTTP/1.1\r\n")
      + String("Host: ") + String (config.openhabHost) + String ("\r\nConnection: close\r\n\r\n");
    client.print (req);
    Serial.print (req);

    bool isError = false;
    
    // wait HTTP_CONNECT_TIMEOUT for response
    unsigned long connectStartTime = millis();
    while (client.available() == 0) {
      if (millis() - connectStartTime > HTTP_CONNECT_TIMEOUT) {
        errorCount++;
        isError = true;
        break;
      }

      yield();
    }

    if (!isError) {
      Serial.print ("Reading response -> ");
      
      // read response lines
      unsigned long readStartTime = millis();

      int ch;
      String resp = "";
      while ((ch = client.read()) != -1) {
        resp += (char)ch;
        
        if (millis() - readStartTime > HTTP_READ_TIMEOUT) {
          errorCount++;
          isError = true;
          break;
        }

        yield();
      }

      Serial.println ("OK");
      
      client.stop();
      return resp;
    } else {
      Serial.println ("ERROR");
    }
  }
  client.stop();
  return String("");
}

/**
 * Returns item name for index.
 * 
 * @param index index.
 * @return OpenHAB item name.
*/
String getOpenhabItem (byte index) {
  return (index == 0) ? String(config.openhabItem1) : String(config.openhabItem2);
}

/**
 * Updates light state on server.
 * 
 * @param lightIndex index.
*/
void updateLightState(byte lightIndex) {
  communicate (String("/CMD?") + getOpenhabItem(lightIndex) + String("=") + (lightState[lightIndex] ? String("ON") : String("OFF")));
}

/**
 * Turns light on/off.
*/
void toggleState (byte lightIndex) {
  Serial.print ("Changing state...");
  lightState[lightIndex] = !lightState[lightIndex];
  if (lightState[lightIndex]) {
    lightOn(lightIndex);
  } else {
    lightOff(lightIndex);
  }
  updateLightState (lightIndex);
}

/**
 * Loop function.
*/
void loop() {
  byte lightIndex;
  lastInteractionTime = 0L;
  bool lastSwitchStates [2];

  for (lightIndex = 0; lightIndex < 2; lightIndex++) {
    lastSwitchStates [lightIndex] = getSwitchState (lightIndex);
    updateLightState (lightIndex);
  }
  
  while (true) {
    if (server) {
      server->handleClient();
    }

    bool doUpdate = (millis() - lastInteractionTime > ITEM_UPDATE_TIME * 1000L);
    
    for (lightIndex = 0; lightIndex < 2; lightIndex++) {
      bool switchState = getSwitchState (lightIndex);
      if (switchState != lastSwitchStates[lightIndex]) {
        delay (150);
        bool newSwitchState = getSwitchState (lightIndex);
        if (switchState == newSwitchState) {
          toggleState (lightIndex);
          lastInteractionTime = millis();
          delay (250);
          lastSwitchStates[lightIndex] = getSwitchState (lightIndex);
        }
      }
      
      if (doUpdate) {
        if (WiFi.status() == WL_CONNECTED) {
          String resp = communicate (String("/rest/items/") + String(getOpenhabItem (lightIndex)) + String("/state"));
              
          if (resp.endsWith ("ON")) {
            lightOn (lightIndex);
            errorCount = 0;
          } else if (resp.endsWith ("OFF")) {
            lightOff (lightIndex);
            errorCount = 0;
          } else {
            Serial.println ("Unknown value:");
            Serial.println (resp);
            Serial.println ("> updating state...");
            updateLightState (lightIndex);
          }
        } else {
          Serial.println ("Wifi not connected!");
          errorCount++;
        }
        
        // when error count reaches ERR_COUNT_FOR_RECONNECT, reconnect WiFi.
        if (errorCount > ERR_COUNT_FOR_RECONNECT) {
          errorCount = 0;
          reconnectWifi();
          createServer();
        }
  
        lastInteractionTime = millis();
      }
    }
   
    yield();
  }
}

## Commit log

2017-01-12 Added some 100n capacitors
    [lightswitchx2_triac.brd, lightswitchx2_triac.sch]
2017-01-13 Modified switch read routine for eliminate interference
    [openhab_light_ctrl.ino]
2017-01-13 Added some capacitors to eliminate interference
    [lightswitchx1_triac.brd, lightswitchx1_triac.sch]
2017-01-16 Added measured power consumption
